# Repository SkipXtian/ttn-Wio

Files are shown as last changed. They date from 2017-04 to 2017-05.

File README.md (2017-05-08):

# GCLora Wio

An Open source weather station that reports tempurature, humidity, barometric pressure and has a RJ11 plug to suit a WH Series tipping bucket rain guage. It has a RFM96 Radio module mounted on the back, transmitting in the 915 - 928 MHz band.</p>

BME280 I2C Address is 0x76<br>
Rain Gauge is on Pin 7 (INT4)<br>

The Arduino example is to connect this Weather station to "The Things Network" through crowd sourced Gateways.
To see a list of gateways head to https://www.thethingsnetwork.org/map </p>

Instructions:

Clone this repo into a directory,<br>
Locate the secrets.h.template file in Arduino/ttn-Wio/<br>
Copy secrets.h.template -> secrets.h and copy details from your TTN console.<br>

This code depends on the lmic library - please make sure you use the version from https://github.com/secluded/arduino-lmic as we made a couple of small changes.
Remove all debugging from config.h for it to compile small enough.

Upload using the Arduino IDE the "Lilypad Arduino USB" board.

In your TTN console you should see data start to arrive. The example is configured to transmit every 5 minutes. You can change this in ttn_Wio.ino, look for TX_INTERVAL = 300; Unit is seconds.

The data should appear in this format: <br>
"32 36 32 38 2C 31 30 31 38 34 36 2C 35 35 34 33 2C 30" Which translates to: <br>
  2  6  2  8  ,  1  0  1  8  4  6  ,  5  5  4  3  ,  0<br>
26.28degress C,      1018.46hPa    ,55.43% Humidity, 0 Rain Ticks

The Tempurature,Barometric and Humidity are divided by 100 to give the decimal places.
Rain Ticks is the count of Rain bucket tipping, multiplying this by 0.2794 will give you rainfall in mm.
We left the processing of Rain for the purpose of indoor use where the sensor might be counting door usage, etc.

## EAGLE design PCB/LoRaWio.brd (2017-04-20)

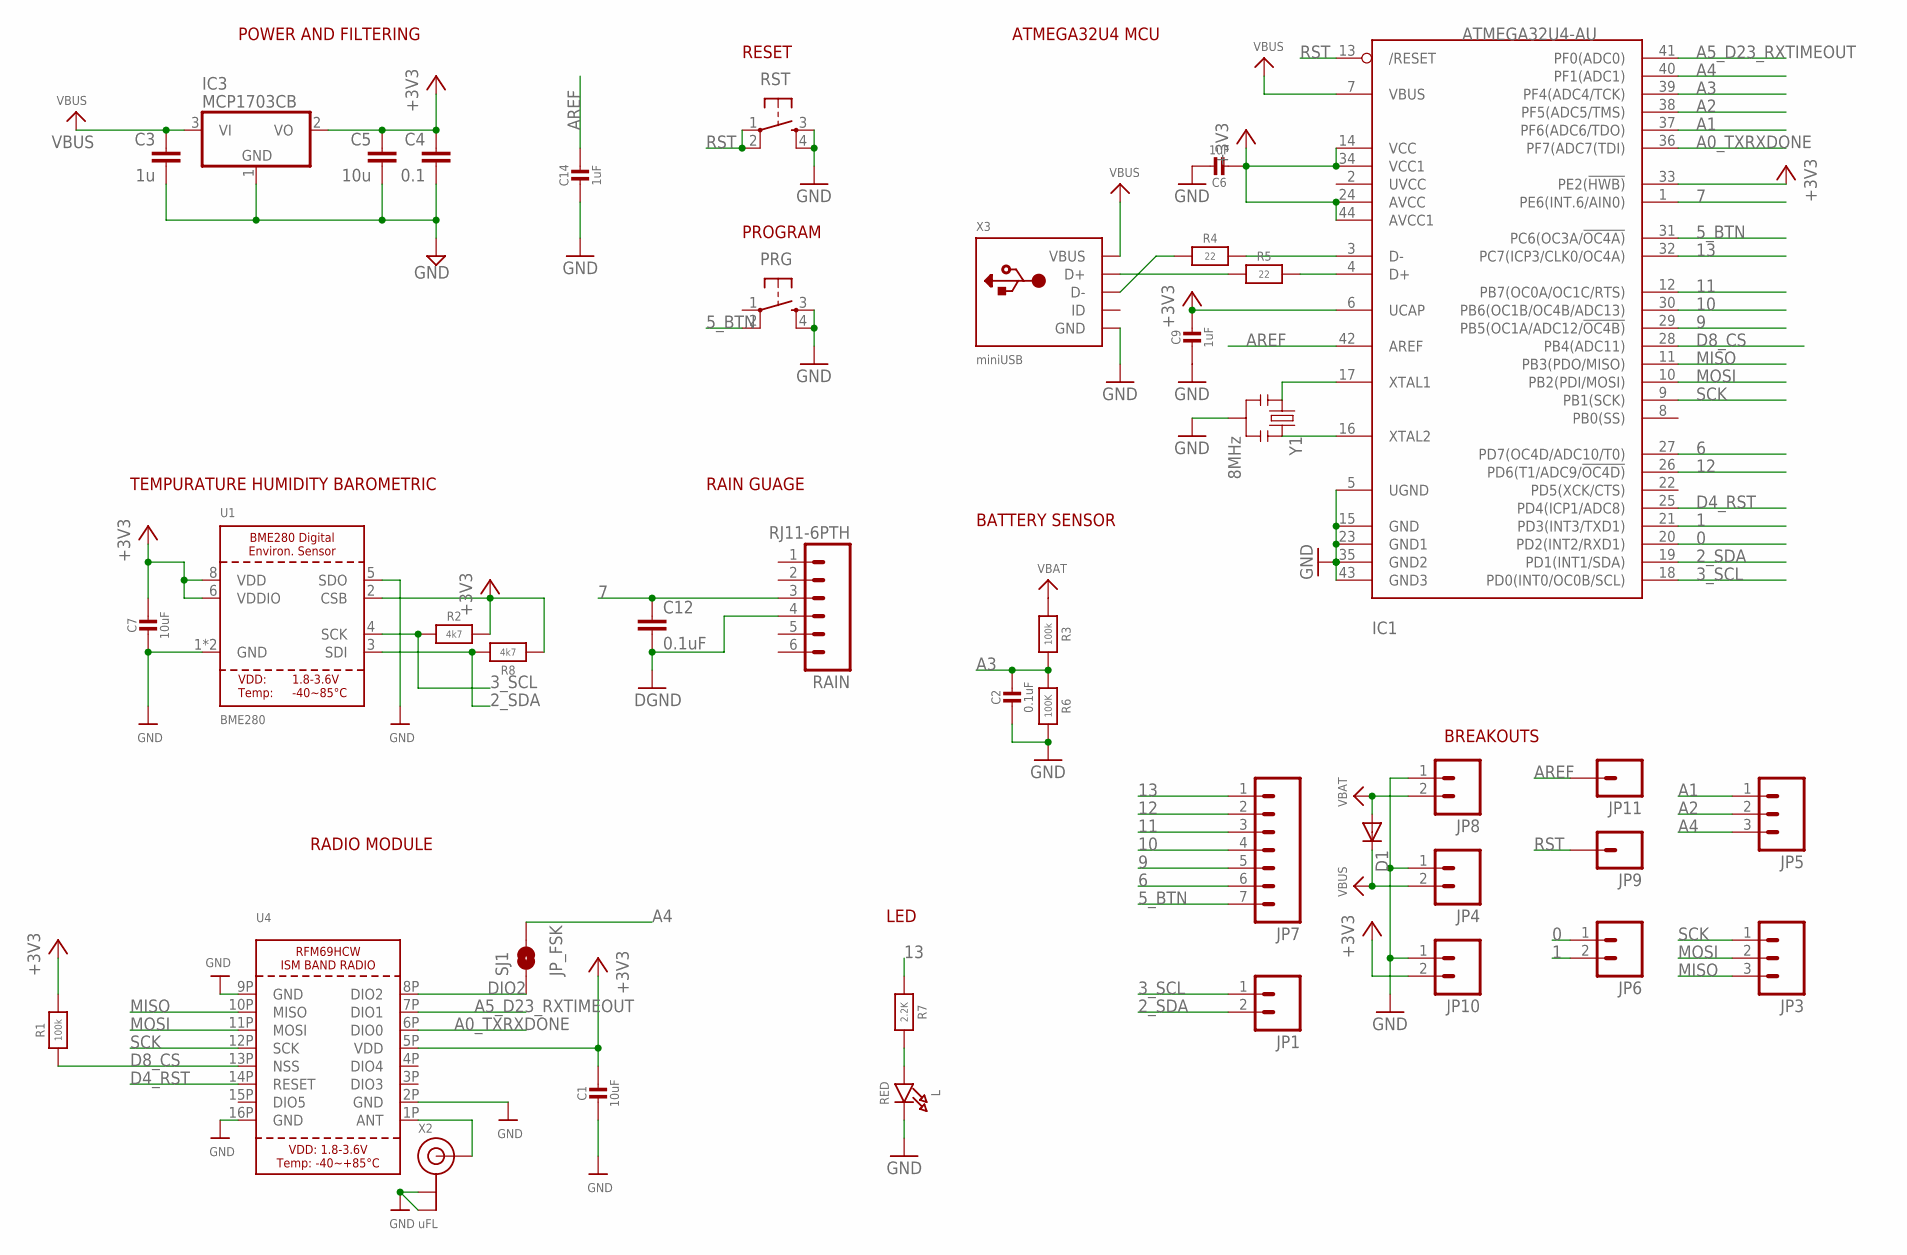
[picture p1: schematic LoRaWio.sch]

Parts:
C1, C7: 10uF; 0805-NO
C2: 0.1uF; 0805-NO
C3: 1u; 0805
C4: 0.1; 0805
C5: 10u; 0805-CAP
C6, C9, C14: 1uF; 0805-NO
C12: 0.1uF; 0805
D1: DIODESOD; SOD-323
IC1: ATMEGA32U4-AU; TQFP44
IC3: MCP1703CB; SOT23
JP1, JP4, JP6, JP8, JP10: M021X02_NO_SILK; 1X02_NO_SILK
JP3, JP5: M031X03_NO_SILK; 1X03_NO_SILK
JP7: M07; 1X07
JP9, JP11: M01PTH_NO_SILK_YES_STOP; 1X01_NO_SILK
L: RED; CHIPLED_0805_NOOUTLINE
PRG: TAC_SWITCHSMD; TACTILE_SWITCH_SMD
R1, R3: 100k; 0805-NO@1
R2, R8: 4k7; 0805-NO@1
R4, R5: 22; 0805-NO@1
R6: 100K; 0805-NO@1
R7: 2.2K; 0805-NO@1
RAIN: RJ11-6PTH; RJ11-6
RST: TAC_SWITCHSMD; TACTILE_SWITCH_SMD
SJ1: JP_FSK; SPARKFUN-PASSIVES_SJ_2S-NO
U1: BME280
U4: RFM69HCW_SMT; RFMHCW_SMT
X2: uFL; U.FL
X3: miniUSB; USB-MINIB_LARGER
Y1: 8MHz; RESONATOR-SMD

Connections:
0: IC1.20 (PD2(INT2/RXD1)), JP6.1
1: IC1.21 (PD3(INT3/TXD1)), JP6.2
2_SDA: IC1.19 (PD1(INT1/SDA)), JP1.2, R8.2, U1.3 (SDI)
3_SCL: IC1.18 (PD0(INT0/OC0B/SCL)), JP1.1, R2.1, U1.4 (SCK)
5_BTN: IC1.31 (PC6(OC3A/!OC4A)), JP7.7, PRG.2
6: IC1.27 (PD7(OC4D/ADC10/T0)), JP7.6
7: C12.1, IC1.1 (PE6(INT.6/AIN0)), RAIN.3
9: IC1.29 (PB5(OC1A/ADC12/!OC4B)), JP7.5
10: IC1.30 (PB6(OC1B/OC4B/ADC13)), JP7.4
11: IC1.12 (PB7(OC0A/OC1C/RTS)), JP7.3
12: IC1.26 (PD6(T1/ADC9/!OC4D)), JP7.2
13: IC1.32 (PC7(ICP3/CLK0/OC4A)), JP7.1, R7.1
+3V3: C1.1, C4.1, C5.1, C6.2, C7.1, C9.1, IC1.6 (UCAP), IC1.14 (VCC), IC1.24 (AVCC), IC1.33 (PE2(!HWB)), IC1.34 (VCC1), IC1.44 (AVCC1), IC3.2 (VO), JP10.2, R1.2, R2.2, R8.1, U1.2 (CSB), U1.6 (VDDIO), U1.8 (VDD), U4.5P (VDD)
A0_TXRXDONE: IC1.36 (PF7(ADC7(TDI)), U4.6P (DIO0)
A1: IC1.37 (PF6(ADC6/TDO)), JP5.1
A2: IC1.38 (PF5(ADC5/TMS)), JP5.2
A3: C2.1, IC1.39 (PF4(ADC4/TCK)), R3.2, R6.1
A4: IC1.40 (PF1(ADC1)), JP5.3, SJ1.2
A5_D23_RXTIMEOUT: IC1.41 (PF0(ADC0)), U4.7P (DIO1)
ANT: U4.1P (ANT), X2.3 (SIGNAL)
AREF: C14.1, IC1.42 (AREF), JP11.1
D4_RST: IC1.25 (PD4(ICP1/ADC8)), U4.14P (RESET)
D8_CS: IC1.28 (PB4(ADC11)), R1.1, U4.13P (NSS)
D+: IC1.4 (D+), R5.2
D-: IC1.3 (D-), R4.2
DIO2: SJ1.1, U4.8P (DIO2)
GND: C1.2, C2.2, C3.2, C4.2, C5.2, C6.1, C7.2, C9.2, C12.2, C14.2, IC1.5 (UGND), IC1.15 (GND), IC1.23 (GND1), IC1.35 (GND2), IC1.43 (GND3), IC3.1 (GND), JP4.1, JP8.1, JP10.1, L.C, PRG.3, PRG.4, R6.2, RAIN.4, RST.3, RST.4, U1.1 (GND), U1.5 (SDO), U1.7 (GND), U4.2P (GND), U4.9P (GND), U4.16P (GND), X2.1 (GND), X2.2 (GND), X3.GND, X3.GND1 (GND), X3.GND2 (GND), X3.GND3 (GND), X3.GND4 (GND), Y1.2
MISO: IC1.11 (PB3(PDO/MISO)), JP3.3, U4.10P (MISO)
MOSI: IC1.10 (PB2(PDI/MOSI)), JP3.2, U4.11P (MOSI)
unnamed: L.A, R7.2
unnamed: IC1.16 (XTAL2), Y1.3
unnamed: IC1.17 (XTAL1), Y1.1
unnamed: R5.1, X3.D+
unnamed: R4.1, X3.D-
RST: IC1.13 (/RESET), JP9.1, RST.1, RST.2
SCK: IC1.9 (PB1(SCK)), JP3.1, U4.12P (SCK)
VBAT: D1.2 (A), JP8.2, R3.1
VBUS: C3.1, D1.1 (C), IC1.7 (VBUS), IC3.3 (VI), JP4.2, X3.VBUS

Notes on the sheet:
POWER AND FILTERING
RESET
ATMEGA32U4 MCU
BREAKOUTS
RADIO MODULE
PROGRAM
RAIN GUAGE
TEMPURATURE HUMIDITY BAROMETRIC
LED
BATTERY SENSOR

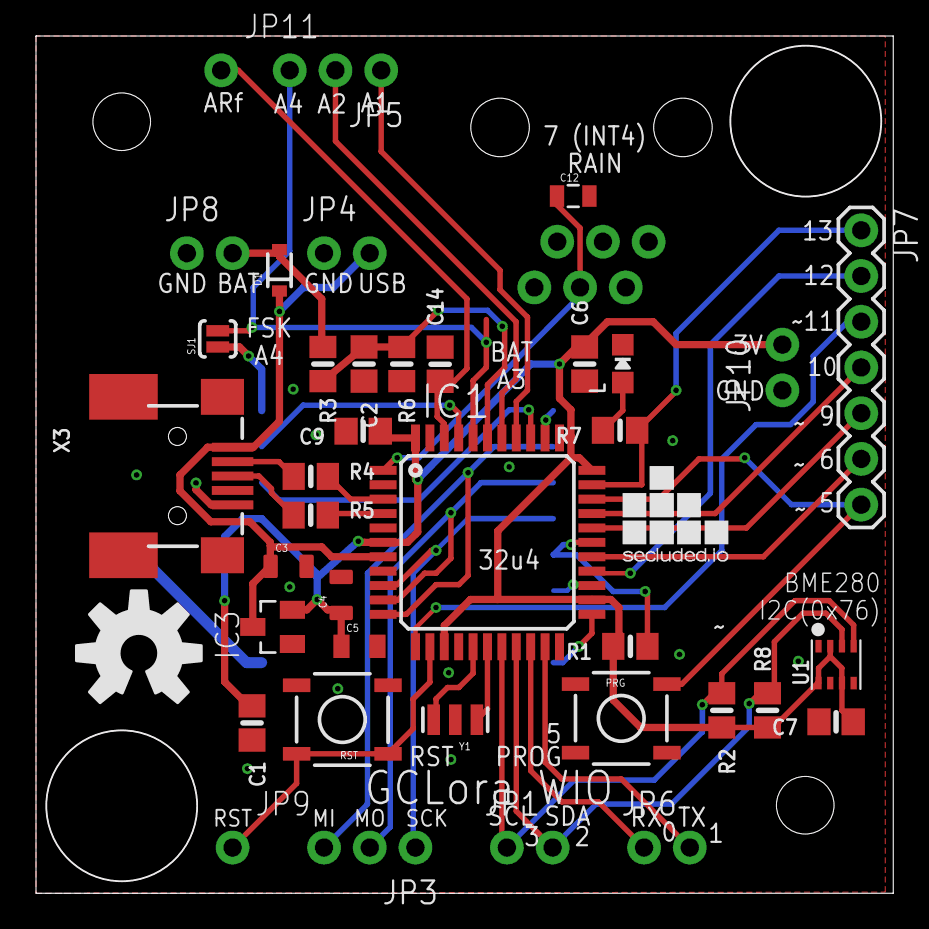
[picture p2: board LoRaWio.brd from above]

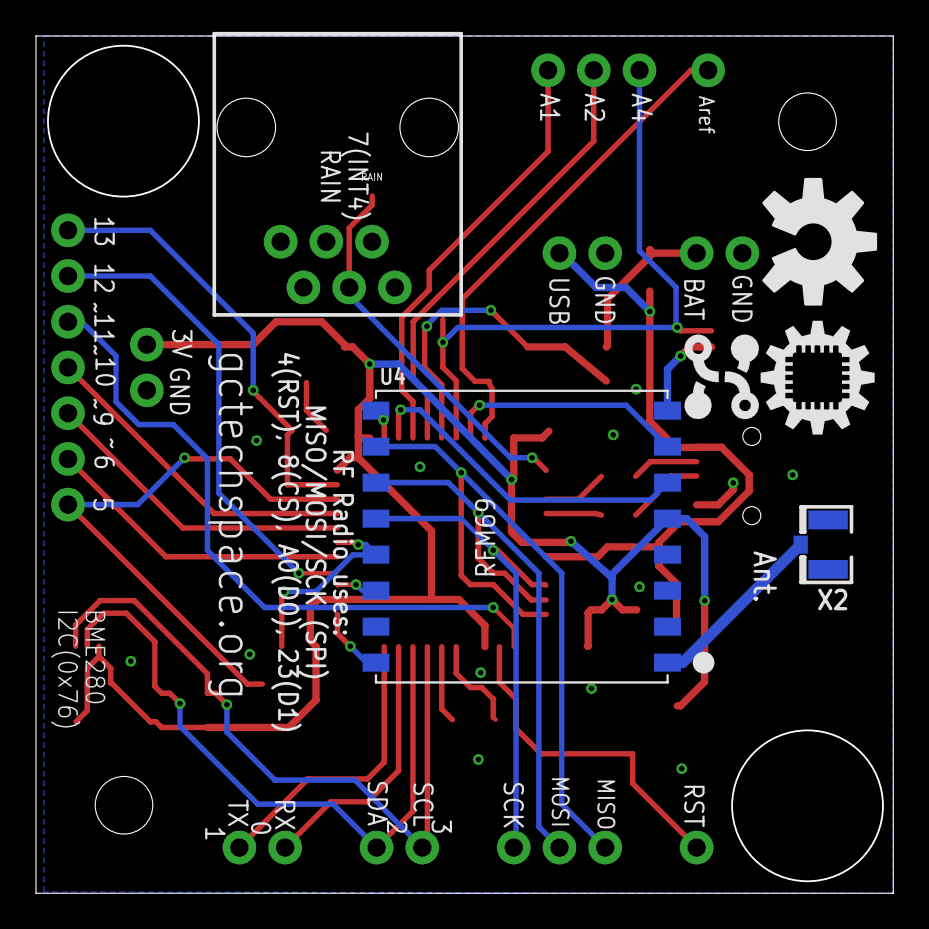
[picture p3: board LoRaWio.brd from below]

Board: 2 copper layers, 47.6 x 47.6 mm, 46 parts (6 on the bottom side), 38 nets.

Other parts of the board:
U$5, U$16: OSHW-LOGO-L
U$6: ESPDUINO_LOGO_5MM
U$7: SECLUDED_5MM
U$15: ID_LOGO_X0.25

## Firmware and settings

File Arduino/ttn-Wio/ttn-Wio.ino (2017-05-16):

//FOR THIS TO COMPILE YOU MUST DISABLE DEBUGGING IN CONFIG.H OF Arduino-lmic

//Defining DEBUG removes the attachInterupt for the rain gauge to allow it to compile small enough.
//#define DEBUG
#ifdef DEBUG
 #define DEBUG_PRINTLN(x)  Serial.println(x)
 #define DEBUG_PRINT(x)  Serial.print(x)
#else
 #define DEBUG_PRINTLN(x)
 #define DEBUG_PRINT(x)
#endif

/***I use a packet decoder in TTN
function Decoder(bytes, port) {
 var decoded = {};

 // Decode bytes to int
 var celciusInt = (bytes[0] << 8) | bytes[1];
 var pressureInt = (bytes[2] << 16) | bytes[3] << 8 | bytes[4];
 var humidityInt = (bytes[5] << 8) | bytes[6];
 // Decode int to float
 decoded.celcius = celciusInt / 100;
 decoded.pressure = pressureInt / 100;
 decoded.humidity = humidityInt / 100;
 decoded.rain = bytes[7] * 0.2794;
 
 return decoded;
}
 */

/*******************************************************************************
 * Copyright (c) 2015 Thomas Telkamp and Matthijs Kooijman
 *
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
 * This example sends a valid LoRaWAN packet with payload "Hello,
 * world!", using frequency and encryption settings matching those of
 * the The Things Network.
 *
 * This uses OTAA (Over-the-air activation), where where a DevEUI and
 * application key is configured, which are used in an over-the-air
 * activation procedure where a DevAddr and session keys are
 * assigned/generated for use with all further communication.
 *
 * Note: LoRaWAN per sub-band duty-cycle limitation is enforced (1% in
 * g1, 0.1% in g2), but not the TTN fair usage policy (which is probably
 * violated by this sketch when left running for longer)!

 * To use this sketch, first register your application and device with
 * the things network, to set or generate an AppEUI, DevEUI and AppKey.
 * Multiple devices can use the same AppEUI, but each device has its own
 * DevEUI and AppKey.
 *
 * Do not forget to define the radio type correctly in config.h.
 *
 *******************************************************************************/
// https://github.com/matthijskooijman/arduino-lmic

#include <lmic.h>
#include <hal/hal.h>
#include <Wire.h>
#include "secrets.h" // moved secret keys referenced below to here
#include <avr/wdt.h>


// Schedule TX every this many seconds (might become longer due to duty
// cycle limitations).
const unsigned TX_INTERVAL = 300; //5mins
#define PACKET_SIZE 8
byte mydata[PACKET_SIZE] = {0};

#define BME280_ADDRESS 0x77
#define RAIN_GUAGE_PIN 7
#define LED_PIN 13
static osjob_t sendjob;


void setup() 
{
  wdt_disable();
  
#ifdef DEBUG
  Serial.begin(115200);
  while (!Serial);
#else
  pinMode(RAIN_GUAGE_PIN, INPUT_PULLUP);
  attachInterrupt(digitalPinToInterrupt(RAIN_GUAGE_PIN), rainGaugeISR, FALLING);
#endif

  DEBUG_PRINTLN(F("Starting WIO"));
  pinMode(LED_PIN, OUTPUT);

  Wire.begin();
  bmeInit();

  // LMIC init
  os_init();
  // Reset the MAC state. Session and pending data transfers will be discarded.
  LMIC_reset();

  LMIC_setClockError(MAX_CLOCK_ERROR * 1 / 100);

  wdt_enable(WDTO_8S);
  
  // Start job (sending automatically starts OTAA too)
  do_send(&sendjob);
}

void loop() 
{
  wdt_reset();
  os_runloop_once();
}

void buildDataPacket()
{
  int16_t temperature; 
  uint32_t pressure;
  uint16_t humidity;
  getBMEData(&temperature, &pressure, &humidity);
  mydata[0] = temperature >> 8;
  mydata[1] = temperature & 0xff;
  mydata[2] = pressure >> 16;
  mydata[3] = (pressure >> 8) & 0xff;
  mydata[4] = pressure & 0xff;
  mydata[5] = humidity >> 8;
  mydata[6] = humidity & 0xff;
  mydata[7] = getRainCount();
}

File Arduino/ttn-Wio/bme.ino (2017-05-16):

int32_t t_fine;

uint16_t dig_T1;
 int16_t dig_T2;
 int16_t dig_T3;
uint16_t dig_P1;
 int16_t dig_P2;
 int16_t dig_P3;
 int16_t dig_P4;
 int16_t dig_P5;
 int16_t dig_P6;
 int16_t dig_P7;
 int16_t dig_P8;
 int16_t dig_P9;
 int8_t  dig_H1;
 int16_t dig_H2;
 int8_t  dig_H3;
 int16_t dig_H4;
 int16_t dig_H5;
 int8_t  dig_H6;

void bmeInit()
{
    uint8_t osrs_t = 1;             //Temperature oversampling x 1
    uint8_t osrs_p = 1;             //Pressure oversampling x 1
    uint8_t osrs_h = 1;             //Humidity oversampling x 1
    uint8_t mode = 3;               //Normal mode
    uint8_t t_sb = 5;               //Tstandby 1000ms
    uint8_t filter = 0;             //Filter off 
    uint8_t spi3w_en = 0;           //3-wire SPI Disable
    
    uint8_t ctrl_meas_reg = (osrs_t << 5) | (osrs_p << 2) | mode;
    uint8_t config_reg    = (t_sb << 5) | (filter << 2) | spi3w_en;
    uint8_t ctrl_hum_reg  = osrs_h;
    
    writeReg(0xF2,ctrl_hum_reg);
    writeReg(0xF4,ctrl_meas_reg);
    writeReg(0xF5,config_reg);
    readTrim();                   
}





void getBMEData(int16_t *temp_cal, uint32_t *press_cal,uint16_t *hum100)  //was 32
{
    uint32_t hum_cal;

    uint32_t hum_raw,temp_raw,pres_raw;
    readData(&hum_raw, &temp_raw, &pres_raw);
    
    *temp_cal = calibration_T(temp_raw);
    *press_cal = calibration_P(pres_raw);
    hum_cal = calibration_H(hum_raw);
    *hum100 = (double)hum_cal / 10.24;

//    Serial.print("TEMP : ");
//    Serial.print(temp_cal);
//    Serial.print(" DegC  PRESS : ");
//    Serial.print(press_cal);
//    Serial.print(" hPa  HUM : ");
//    Serial.print(hum100);
//    Serial.println(" % ");
}

void readTrim()
{
    uint8_t data[32],i=0;
    writeReg(0, 0x88);
    Wire.requestFrom(BME280_ADDRESS,24);
    while(Wire.available()){
        data[i] = Wire.read();
        i++;
    }

    writeReg(0, 0xA1);
    Wire.requestFrom(BME280_ADDRESS,1);
    data[i] = Wire.read();
    i++;

    writeReg(0, 0xE1);
    Wire.requestFrom(BME280_ADDRESS,7);
    while(Wire.available()){
        data[i] = Wire.read();
        i++;    
    }
    dig_T1 = (data[1] << 8) | data[0];
    dig_T2 = (data[3] << 8) | data[2];
    dig_T3 = (data[5] << 8) | data[4];
    dig_P1 = (data[7] << 8) | data[6];
    dig_P2 = (data[9] << 8) | data[8];
    dig_P3 = (data[11]<< 8) | data[10];
    dig_P4 = (data[13]<< 8) | data[12];
    dig_P5 = (data[15]<< 8) | data[14];
    dig_P6 = (data[17]<< 8) | data[16];
    dig_P7 = (data[19]<< 8) | data[18];
    dig_P8 = (data[21]<< 8) | data[20];
    dig_P9 = (data[23]<< 8) | data[22];
    dig_H1 = data[24];
    dig_H2 = (data[26]<< 8) | data[25];
    dig_H3 = data[27];
    dig_H4 = (data[28]<< 4) | (0x0F & data[29]);
    dig_H5 = (data[30] << 4) | ((data[29] >> 4) & 0x0F);
    dig_H6 = data[31];   
}

void writeReg(uint8_t reg_address, uint8_t data)
{
    Wire.beginTransmission(BME280_ADDRESS);
    if(reg_address != 0) Wire.write(reg_address);
    Wire.write(data);
    Wire.endTransmission();    
}


void readData(uint32_t *hum_raw, uint32_t *temp_raw, uint32_t *pres_raw)
{
    int i = 0;
    uint32_t data[8];
    writeReg(0, 0xF7);
    Wire.requestFrom(BME280_ADDRESS,8);
    while(Wire.available()){
        data[i] = Wire.read();
        i++;
    }
    *pres_raw = (data[0] << 12) | (data[1] << 4) | (data[2] >> 4);
    *temp_raw = (data[3] << 12) | (data[4] << 4) | (data[5] >> 4);
    *hum_raw  = (data[6] << 8) | data[7];
}


int32_t calibration_T(int32_t adc_T)
{
    
    int32_t var1, var2, T;
    var1 = ((((adc_T >> 3) - ((int32_t)dig_T1<<1))) * ((int32_t)dig_T2)) >> 11;
    var2 = (((((adc_T >> 4) - ((int32_t)dig_T1)) * ((adc_T>>4) - ((int32_t)dig_T1))) >> 12) * ((int32_t)dig_T3)) >> 14;
    
    t_fine = var1 + var2;
    T = (t_fine * 5 + 128) >> 8;
    return T; 
}

uint32_t calibration_P(int32_t adc_P)
{
    int32_t var1, var2;
    uint32_t P;
    var1 = (((int32_t)t_fine)>>1) - (int32_t)64000;
    var2 = (((var1>>2) * (var1>>2)) >> 11) * ((int32_t)dig_P6);
    var2 = var2 + ((var1*((int32_t)dig_P5))<<1);
    var2 = (var2>>2)+(((int32_t)dig_P4)<<16);
    var1 = (((dig_P3 * (((var1>>2)*(var1>>2)) >> 13)) >>3) + ((((int32_t)dig_P2) * var1)>>1))>>18;
    var1 = ((((32768+var1))*((int32_t)dig_P1))>>15);
    if (var1 == 0)
    {
        return 0;
    }    
    P = (((uint32_t)(((int32_t)1048576)-adc_P)-(var2>>12)))*3125;
    if(P<0x80000000)
    {
       P = (P << 1) / ((uint32_t) var1);   
    }
    else
    {
        P = (P / (uint32_t)var1) * 2;    
    }
    var1 = (((int32_t)dig_P9) * ((int32_t)(((P>>3) * (P>>3))>>13)))>>12;
    var2 = (((int32_t)(P>>2)) * ((int32_t)dig_P8))>>13;
    P = (uint32_t)((int32_t)P + ((var1 + var2 + dig_P7) >> 4));
    return P;
}

uint32_t calibration_H(int32_t adc_H)
{
    int32_t v_x1;
    
    v_x1 = (t_fine - ((int32_t)76800));
    v_x1 = (((((adc_H << 14) -(((int32_t)dig_H4) << 20) - (((int32_t)dig_H5) * v_x1)) + 
              ((int32_t)16384)) >> 15) * (((((((v_x1 * ((int32_t)dig_H6)) >> 10) * 
              (((v_x1 * ((int32_t)dig_H3)) >> 11) + ((int32_t) 32768))) >> 10) + (( int32_t)2097152)) * 
              ((int32_t) dig_H2) + 8192) >> 14));
   v_x1 = (v_x1 - (((((v_x1 >> 15) * (v_x1 >> 15)) >> 7) * ((int32_t)dig_H1)) >> 4));
   v_x1 = (v_x1 < 0 ? 0 : v_x1);
   v_x1 = (v_x1 > 419430400 ? 419430400 : v_x1);
   return (uint32_t)(v_x1 >> 12);   
}

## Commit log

2017-04-20 Added PCB and cleaned directory structure
    [LoRaWio.brd, LoRaWio.sch]
2017-05-08 Added Watchdog timer

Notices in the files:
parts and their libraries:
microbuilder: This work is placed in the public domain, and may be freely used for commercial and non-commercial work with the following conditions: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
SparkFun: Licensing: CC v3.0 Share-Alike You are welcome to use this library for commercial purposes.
